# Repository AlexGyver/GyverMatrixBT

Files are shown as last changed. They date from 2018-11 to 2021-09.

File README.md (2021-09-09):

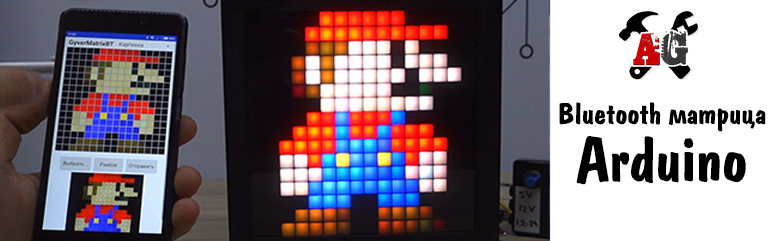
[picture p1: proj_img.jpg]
PROJECT_PHOTO

# Bluetooth адресная матрица на Arduino
* [Описание проекта](#chapter-0)
* [Папки проекта](#chapter-1)
* [Схемы подключения](#chapter-2)
* [Материалы и компоненты](#chapter-3)
* [Как скачать и прошить](#chapter-4)
* [FAQ](#chapter-5)
* [Полезная информация](#chapter-6)
AlexGyver YouTube (https://www.youtube.com/channel/UCgtAOyEQdAyjvm9ATCi_Aig?sub_confirmation=1)

## Описание проекта
Матрица на адресных светодиодах с управлением по Bluetooth  
Гайд по матрицам: https://alexgyver.ru/matrix_guide/  
Страница проекта на сайте: https://alexgyver.ru/gyvermatrixbt/  
Описания к новыем версиям прошивок и приложений смотри на странице проекта    
#### Особенности:
 - Управление со смартфона по Bluetooth
#### Режимы:
 - Рисование
 - Загрузка картинок
 - Бегущая строка  
#### Эффекты:
 - "Дыхание" яркости
 - Смена цвета
 - Снегопад
 - Блуждающий кубик
 - Радуга
 - Огонь
 - The Matrix
 - Летающие частицы
 - Линии  
#### Игры:
 - Змейка
 - Tетриc
 - Лабиринт  
#### Возможности:
- Автоподключение к матрице при запуске
- Настройки яркости и скорости отображения
- Использование акселерометра в играх

## Папки
**ВНИМАНИЕ! Если это твой первый опыт работы с Arduino, читай [инструкцию](#chapter-4)**
- **libraries** - библиотеки проекта. Заменить имеющиеся версии (в этом проекте внешних библиотек нет)
- **firmware** - прошивки для Arduino
- **schemes** - схемы подключения компонентов
- **Android** - файлы с приложениями, примерами для Android и Thunkable
- **3Dprint** - файлы для печати и исходники

## Схемы
SCHEME

## Материалы и компоненты
### Ссылки оставлены на магазины, с которых я закупаюсь уже не один год
Полный список компонентов есть в статье https://alexgyver.ru/matrix_guide/
- Arduino NANO https://ali.ski/RJYuq  https://ali.ski/8JonUm  https://ali.ski/0DIg3
- Bluetooth HC-06 https://ali.ski/nrJ-G  https://ali.ski/0H5Vk  https://ali.ski/xC5vwp
- Матрицы разные https://ali.ski/ft9Y6T
- Лента https://ali.ski/cXIgB1
- Модульная гирлянда https://ali.ski/qrVjv
- Резисторы https://ali.ski/sr6Xy
- БП 5 Вольт https://ali.ski/HkrNAG  https://ali.ski/Y-6VK

## Вам скорее всего пригодится
* [Всё для пайки (паяльники и примочки)](http://alexgyver.ru/all-for-soldering/)
* [Недорогие инструменты](http://alexgyver.ru/my_instruments/)
* [Все существующие модули и сенсоры Arduino](http://alexgyver.ru/arduino_shop/)
* [Электронные компоненты](http://alexgyver.ru/electronics/)
* [Аккумуляторы и зарядные модули](http://alexgyver.ru/18650/)

## Как скачать и прошить
* [Первые шаги с Arduino](http://alexgyver.ru/arduino-first/) - ультра подробная статья по началу работы с Ардуино, ознакомиться первым делом!
* Скачать архив с проектом
> На главной странице проекта (где ты читаешь этот текст) вверху справа зелёная кнопка **Clone or download**, вот её жми, там будет **Download ZIP**
* Установить библиотеки в  
`C:\Program Files (x86)\Arduino\libraries\` (Windows x64)  
`C:\Program Files\Arduino\libraries\` (Windows x86)
* **Подключить внешнее питание 5 Вольт**
* Подключить Ардуино к компьютеру
* Запустить файл прошивки (который имеет расширение .ino)
* Настроить IDE (COM порт, модель Arduino, как в статье выше)
* Настроить что нужно по проекту
* Нажать загрузить
* Скачать GyverMatrixBT с Play Market
* Пользоваться  

## Настройки в коде
    USE_BUTTONS 0       // использовать физические кнопки управления (0 нет, 1 да)
    BUTT_UP 3           // кнопка вверх
    BUTT_DOWN 5         // кнопка вниз
    BUTT_LEFT 2         // кнопка влево
    BUTT_RIGHT 4        // кнопка вправо

    LED_PIN 6           // пин ленты
    BRIGHTNESS 60       // стандартная маскимальная яркость (0-255)

    WIDTH 16            // ширина матрицы
    HEIGHT 16           // высота матрицы

    MATRIX_TYPE 0       // тип матрицы: 0 - зигзаг, 1 - последовательная
    CONNECTION_ANGLE 0  // угол подключения: 0 - левый нижний, 1 - левый верхний, 2 - правый верхний, 3 - правый нижний
    STRIP_DIRECTION 0   // направление ленты из угла: 0 - вправо, 1 - вверх, 2 - влево, 3 - вниз

    SCORE_SIZE 0        // размер букв счёта в игре. 0 - маленький (для 8х8), 1 - большой
    FONT_TYPE 1			// (0 / 1) два вида маленького шрифта

    GLOBAL_COLOR_1 CRGB::Green    // основной цвет №1 для игр
    GLOBAL_COLOR_2 CRGB::Orange   // основной цвет №2 для игр

## FAQ
### Основные вопросы
В: Как скачать с этого грёбаного сайта?  
О: На главной странице проекта (где ты читаешь этот текст) вверху справа зелёная кнопка **Clone or download**, вот её жми, там будет **Download ZIP**

В: Скачался какой то файл .zip, куда его теперь?  
О: Это архив. Можно открыть стандартными средствами Windows, но думаю у всех на компьютере установлен WinRAR, архив нужно правой кнопкой и извлечь.

В: Я совсем новичок! Что мне делать с Ардуиной, где взять все программы?  
О: Читай и смотри видос http://alexgyver.ru/arduino-first/

В: Вылетает ошибка загрузки / компиляции!
О: Читай тут: https://alexgyver.ru/arduino-first/#step-5

В: Сколько стоит?  
О: Ничего не продаю.

### Вопросы по этому проекту

## Полезная информация
* [Мой сайт](http://alexgyver.ru/)
* [Основной YouTube канал](https://www.youtube.com/channel/UCgtAOyEQdAyjvm9ATCi_Aig?sub_confirmation=1)
* [YouTube канал про Arduino](https://www.youtube.com/channel/UC4axiS76D784-ofoTdo5zOA?sub_confirmation=1)
* [Мои видеоуроки по пайке](https://www.youtube.com/playlist?list=PLOT_HeyBraBuMIwfSYu7kCKXxQGsUKcqR)
* [Мои видеоуроки по Arduino](http://alexgyver.ru/arduino_lessons/)

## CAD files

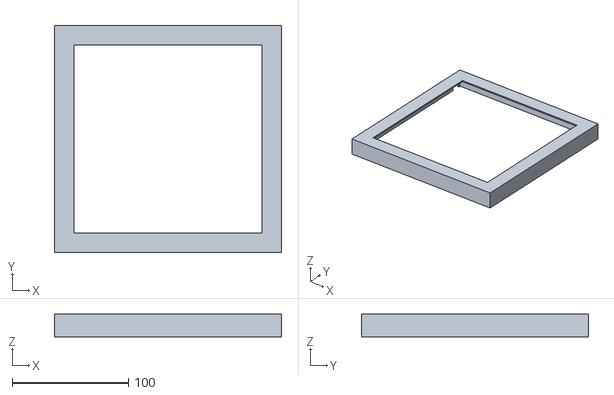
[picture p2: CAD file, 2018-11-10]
3Dprint/Деталь2.stl
195.6 x 195.6 x 19.4

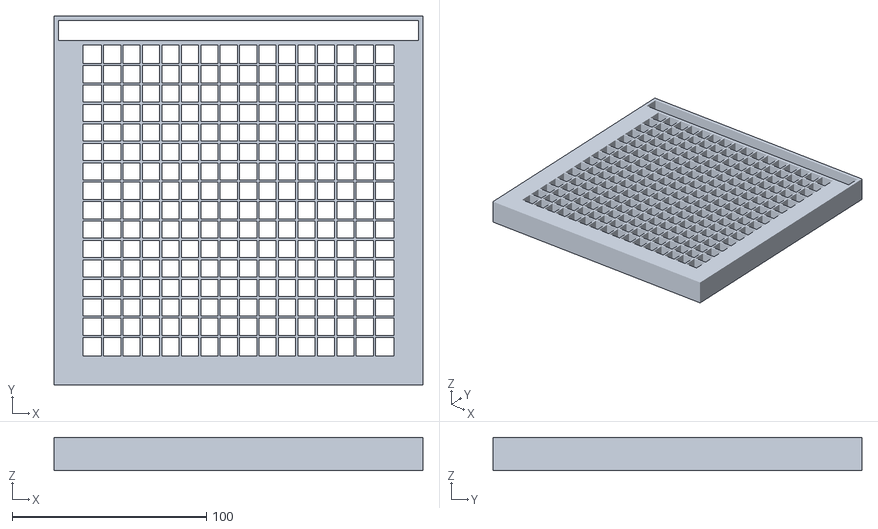
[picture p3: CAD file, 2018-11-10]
3Dprint/Деталь.stl
190.0 x 190.0 x 17.0

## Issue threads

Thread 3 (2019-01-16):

Бегущая строка

lazyan, 2019-01-16:
1. Замечены глюки при отображении бегущей строки. Для устранения комментируем или удаляем:

`FastLED.show();`

в модуле runningText.ino, т.к. он дублируется в custom.ino.

2. В функции drawLetter (модуль runningText.ino) не имеет смысла:

```
...
else drawPixelXY(offset + i, TEXT_HEIGHT + j, 0x000000);
...
else drawPixelXY(i, offset + TEXT_HEIGHT + j, 0x000000);
```

Т.к. до этого экран очищается командой FastLED.clear();

3. Если не использовать блютуз, то скорость прокрутки не зависит от параметра D_TEXT_SPEED из-за условия (модуль runningText.ino):

`if (scrollTimer.isReady() || (!BTcontrol && !gamemodeFlag)) {`

Я просто заменил на:

`if (scrollTimer.isReady()) {`

4. А вообще прикольная хрень )))

buzzik, 2019-12-20:
Подтверждаю глюк на NodeMCU из-за этого бага, закоментил
`    if (offset < -j * (LET_WIDTH + SPACE)) {    // строка убежала
      offset = WIDTH + 3;
      fullTextFlag = true;
    }
    // FastLED.show();
  }`

в модуле runningText.ino

баг пропал, работает отлично. Спасибо Сфори

dimka-36, 2020-02-18:
Целую неделю пытался побороть сей глюк. До сих пор не понимаю как это условие влияло на него :)
 lazyan, спасибо!

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

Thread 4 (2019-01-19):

BT модуль

Irek66, 2019-01-19:
Можно ли для проекта использовать модуль BT типа HM-10 без изменения скетча? А также модуль часов DS1302? Если необходимы изменения, то насколько сложные? Может проще приобрести модули как в проекте.
Спасибо.

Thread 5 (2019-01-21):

Виснет esp8266

SergeyZalozniy, 2019-01-21:
Доброго времени.
Заметил такой баг, не знаю как исправить.
При разных эффектах где используются все диоды esp8266 часто зависает.
Например в режиме радуга или разные "noise", остальные режимы работают отлично весь день.
Спасибо.

SergeyZalozniy, 2019-01-21:
@lazyan а вы сможете сделать fork и залить свои изминеня? Буду очень признателен.

lazyan, 2019-01-21:
Уже!

Best regards,
Anton Horpynich

пн, 21 янв. 2019 г. в 23:47, SergeyZalozniy <notifications@github.com>:

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

lazyan, 2019-01-21:
Уже закомитил

Best regards,
Anton Horpynich

пн, 21 янв. 2019 г. в 23:47, SergeyZalozniy <notifications@github.com>:

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

SergeyZalozniy, 2019-01-22:
Решил проблему.
Оказалось все просто, я использую NodeMCU v3 LoLin,
подключена она напрямую к блоку питания 5v 20a, туда же и лента подключена.
По совету Алекса я поставил напряжение в 4.5v, а по "мануалу" должно быть от 6 - 20v. При включении всей ленты видимо чуток идет просадка, что и приводит к зависанию.
Исправил - отдельное питание для платы помогло.

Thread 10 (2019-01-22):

Вынести прошивку в отдельный репозиторий

Sviatoy, 2019-01-22:
Собственно сейчас, т.к. новая версия делается через добавление ещё одной папки, нет возможности нормально разрабатывать.
Если вынести в отдельный репозиторий, то можно делать релизы. Там можно будет скачивать отдельный архив с одной версией, будет понятно какие изменения

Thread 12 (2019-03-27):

"Нестандартный" размер матрицы

jhnf, 2019-03-27:
Приветствую! Хочу сделать матрицу "нестандартного" размера 4x64 - вдоль крыши дома. Собственно какие из эффектов будут работать на таком размере, а какие нет?

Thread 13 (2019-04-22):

Добавление цветомузыки в качестве эффекта

aka-inc, 2019-04-22:
Есть ли возможность прикрутить эффект цветомузыки? Через микрофон (LineOut) на единственный аналоговый вход ESP8266? Также можно добавить включение следующего эффекта хлопком в ладоши.

Спаял матрицу 15х20 на весь потолок размером 3,8х3,5 метра на микроконтроллере ESP8266-12E, который разместил внутри блока питания 5В 20А. Чтобы избавиться от наводок и глюков, использовал коаксиальный кабель на DIN светодиодной ленты, ферритовое кольцо на линии питания контроллера, обвязку из конденсаторов, а также пришлось понизить напряжение на светодиодах до 4.4В. Глюки проявляются на контрастных режимах с резким переключением яркости диодов, некоторые эффекты вообще не работают, и добавление конденсатора в линию питания контроллера и ленты ничего не даёт. Они явно связаны с всплесками/просадками напряжения при изменении яркости. Может память контроллера заполняется случайным мусором от каких-то наводок. А при пониженном напряжении ничего не глючит, нет спонтанных вспышек и артефактов, но яркость сильно ниже, и цветовой спектр диодов становится очень узкий.  Увеличение расстояния контроллера от блока питания и его экранирование фольгой не влияют на глюки, выпаивал все лишние кнопки, блютузы и прочее, добавлял конденсаторы, менял ESP8266 на ардуину Mega с её 5В питания - ничего не спасает от глюков, только понижение напряжения до 4.4В.

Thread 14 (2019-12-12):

Просьба указать лицензию

smartynov, 2019-12-12:
В настоящее время в репозитории проекта отсутствует указание, по какой лицензии он распространяется (обычно принято это делать в отдельном файле LICENSE). Соответственно, непонятно, является ли этот проект open source и можно ли делать форки проекта и под какой лицензией их распространять. Прошу указать лицензию (рекомендую выбрать MIT).

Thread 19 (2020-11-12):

Проблеми з повзунком "Швидкість"

80Stepko08, 2020-11-12:
1. Мінімальне значення - максимальна швидкість
То ж можна легко поправити 255-знач
Для ігор  то 255-знач множиться на 4 щоб було повільніше
2. Шуми(Божевілля,Хмари і інші) покадрові, хоча можна зробити плавними

Closed 2023-07-04.

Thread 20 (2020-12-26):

В эффектах и бегущей строке не учитывается настройка SEGMENTS

AlexDerev, 2020-12-26:
Если строить матрицу из лент, например 10 х 1м (30 led/м), то матрицу можно расписать как
WIDTH 10
HEIGHT 30
SEGMENTS 1
Или, если хотим уменьшить размер обрабатываемой матрицы (и затраты памяти) и за 1 pix отвечают 2 светодиода, то матрица будет 10х15
WIDTH 10
HEIGHT 15
SEGMENTS 2
Во втором случае во многих эффектах работает только половина матрицы с искажениями, а высота букв в строке так и останется в 8 светодиодов.

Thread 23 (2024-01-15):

Не работает на Mega 2560

P55-rgb, 2024-01-15:
Добрый день.
На нано программа запустилась, добавил диодов, кончилась память, прошил Mega 2560 и не понятно почему не работает блютуз. Без связи по блютуз, Мега 2560 выводит текст на диоды красным цветом КРАСНЫЙ.
Не нашел в описании куда подключать блутуз на Мега 2560.
Подключил блутуз на ТХ0, RX0.

В чём проблема?

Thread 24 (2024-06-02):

Вопрос об другой версии приложения

N-hope, 2024-06-02:
я ранее писал под другим проэктом(из этой же тематики).
У вас на станице проэкта ( https://alexgyver.ru/gyvermatrixbt/ ) есть англоязычная версия. Есть ли возвомность посмотреть ее .aia файл или хотя бы фото всех блоков, как и в других версиях?

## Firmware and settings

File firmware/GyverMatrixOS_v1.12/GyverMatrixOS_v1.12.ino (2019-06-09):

/*
  Скетч к проекту "Адресная матрица"
  Гайд по постройке матрицы: https://alexgyver.ru/matrix_guide/
  Страница проекта (схемы, описания): https://alexgyver.ru/GyverMatrixBT/
  Подробное описание прошивки: https://alexgyver.ru/gyvermatrixos-guide/
  Исходники на GitHub: https://github.com/AlexGyver/GyverMatrixBT/
  Нравится, как написан код? Поддержи автора! https://alexgyver.ru/support_alex/
  Автор: AlexGyver Technologies, 2018
  https://AlexGyver.ru/
*/

// GyverMatrixOS
// Версия прошивки 1.12, совместима с приложением GyverMatrixBT версии 1.12 и выше
// 1.12 - поправлен косяк с кнопкой SET на wemos/nodemcu

// ************************ МАТРИЦА *************************
// если прошивка не лезет в Arduino NANO - отключай режимы! Строка 60 и ниже

#define BRIGHTNESS 150        // стандартная маскимальная яркость (0-255)
#define CURRENT_LIMIT 2000    // лимит по току в миллиамперах, автоматически управляет яркостью (пожалей свой блок питания!) 0 - выключить лимит

#define WIDTH 16              // ширина матрицы
#define HEIGHT 16             // высота матрицы
#define SEGMENTS 1            // диодов в одном "пикселе" (для создания матрицы из кусков ленты)

#define COLOR_ORDER GRB       // порядок цветов на ленте. Если цвет отображается некорректно - меняйте. Начать можно с RGB

#define MATRIX_TYPE 0         // тип матрицы: 0 - зигзаг, 1 - параллельная
#define CONNECTION_ANGLE 0    // угол подключения: 0 - левый нижний, 1 - левый верхний, 2 - правый верхний, 3 - правый нижний
#define STRIP_DIRECTION 0     // направление ленты из угла: 0 - вправо, 1 - вверх, 2 - влево, 3 - вниз
// при неправильной настрйоке матрицы вы получите предупреждение "Wrong matrix parameters! Set to default"
// шпаргалка по настройке матрицы здесь! https://alexgyver.ru/matrix_guide/

#define MCU_TYPE 0            // микроконтроллер: 
//                            0 - AVR (Arduino NANO/MEGA/UNO)
//                            1 - ESP8266 (NodeMCU, Wemos D1)
//                            2 - STM32 (Blue Pill)

// ******************** ЭФФЕКТЫ И РЕЖИМЫ ********************
#define D_TEXT_SPEED 100      // скорость бегущего текста по умолчанию (мс)
#define D_EFFECT_SPEED 80     // скорость эффектов по умолчанию (мс)
#define D_GAME_SPEED 250      // скорость игр по умолчанию (мс)
#define D_GIF_SPEED 80        // скорость гифок (мс)
#define DEMO_GAME_SPEED 60    // скорость игр в демо режиме (мс)

boolean AUTOPLAY = 1;         // 0 выкл / 1 вкл автоматическую смену режимов (откл. можно со смартфона)
int AUTOPLAY_PERIOD = 10;     // время между авто сменой режимов (секунды)
#define IDLE_TIME 10          // время бездействия кнопок или Bluetooth (в секундах) после которого запускается автосмена режимов и демо в играх

// о поддерживаемых цветах читай тут https://alexgyver.ru/gyvermatrixos-guide/
#define GLOBAL_COLOR_1 CRGB::Green    // основной цвет №1 для игр
#define GLOBAL_COLOR_2 CRGB::Orange   // основной цвет №2 для игр

#define SCORE_SIZE 0          // размер символов счёта в игре. 0 - маленький для 8х8 (шрифт 3х5), 1 - большой (шрифт 5х7)
#define FONT_TYPE 1           // (0 / 1) два вида маленького шрифта в выводе игрового счёта

// ************** ОТКЛЮЧЕНИЕ КОМПОНЕНТОВ СИСТЕМЫ (для экономии памяти) *************
// внимание! отключение модуля НЕ УБИРАЕТ его эффекты из списка воспроизведения!
// Это нужно сделать вручную во вкладке custom, удалив ненужные функции

#define USE_BUTTONS 1         // использовать физические кнопки управления играми (0 нет, 1 да)
#define BT_MODE 1             // использовать блютус (0 нет, 1 да)
#define USE_NOISE_EFFECTS 1   // крутые полноэкранные эффекты (0 нет, 1 да) СИЛЬНО ЖРУТ ПАМЯТЬ!!!11
#define USE_FONTS 1           // использовать буквы (бегущая строка) (0 нет, 1 да)
#define USE_CLOCK 0           // использовать часы (0 нет, 1 да)

// игры
#define USE_SNAKE 0           // игра змейка (0 нет, 1 да)
#define USE_TETRIS 0          // игра тетрис (0 нет, 1 да)
#define USE_MAZE 0            // игра лабиринт (0 нет, 1 да)
#define USE_RUNNER 0          // игра бегалка-прыгалка (0 нет, 1 да)
#define USE_FLAPPY 0          // игра flappy bird
#define USE_ARKAN 0           // игра арканоид

// ****************** ПИНЫ ПОДКЛЮЧЕНИЯ *******************
// Arduino (Nano, Mega)
#if (MCU_TYPE == 0)
#define LED_PIN 6           // пин ленты
#define BUTT_UP 3           // кнопка вверх
#define BUTT_DOWN 5         // кнопка вниз
#define BUTT_LEFT 2         // кнопка влево
#define BUTT_RIGHT 4        // кнопка вправо
#define BUTT_SET 7          // кнопка выбор/игра

// пины подписаны согласно pinout платы, а не надписям на пинах!
// esp8266 - плату выбирал Wemos D1 R1
#elif (MCU_TYPE == 1)
#define LED_PIN 2           // пин ленты
#define BUTT_UP 14          // кнопка вверх
#define BUTT_DOWN 13        // кнопка вниз
#define BUTT_LEFT 0         // кнопка влево
#define BUTT_RIGHT 12       // кнопка вправо
#define BUTT_SET 15         // кнопка выбор/игра

// STM32 (BluePill) - плату выбирал STM32F103C
#elif (MCU_TYPE == 2)
#define LED_PIN PB12         // пин ленты
#define BUTT_UP PA1          // кнопка вверх
#define BUTT_DOWN PA3        // кнопка вниз
#define BUTT_LEFT PA0        // кнопка влево
#define BUTT_RIGHT PA2       // кнопка вправо
#define BUTT_SET PA4         // кнопка выбор/игра
#endif

// ******************************** ДЛЯ РАЗРАБОТЧИКОВ ********************************
#define DEBUG 0
#define NUM_LEDS WIDTH * HEIGHT * SEGMENTS

#define RUNNING_STRING 0
#define CLOCK_MODE 1
#define GAME_MODE 2
#define MADNESS_NOISE 3
#define CLOUD_NOISE 4
#define LAVA_NOISE 5
#define PLASMA_NOISE 6
#define RAINBOW_NOISE 7
#define RAINBOWSTRIPE_NOISE 8
#define ZEBRA_NOISE 9
#define FOREST_NOISE 10
#define OCEAN_NOISE 11
#define SNOW_ROUTINE 12
#define SPARKLES_ROUTINE 13
#define MATRIX_ROUTINE 14
#define STARFALL_ROUTINE 15
#define BALL_ROUTINE 16
#define BALLS_ROUTINE 17
#define RAINBOW_ROUTINE 18
#define RAINBOWDIAGONAL_ROUTINE 19
#define FIRE_ROUTINE 20
#define IMAGE_MODE 21

#if (MCU_TYPE == 1)
#define FASTLED_INTERRUPT_RETRY_COUNT 0
#define FASTLED_ALLOW_INTERRUPTS 0
#include <ESP8266WiFi.h>
#endif

#include "FastLED.h"
CRGB leds[NUM_LEDS];
String runningText = "";

static const byte maxDim = max(WIDTH, HEIGHT);
byte buttons = 4;   // 0 - верх, 1 - право, 2 - низ, 3 - лево, 4 - не нажата
int globalBrightness = BRIGHTNESS;
byte globalSpeed = 200;
uint32_t globalColor = 0x00ff00;   // цвет при запуске зелёный
byte breathBrightness;
boolean loadingFlag = true;
byte frameNum;
int gameSpeed = DEMO_GAME_SPEED;
boolean gameDemo = true;
boolean idleState = true;  // флаг холостого режима работы
boolean BTcontrol = false;  // флаг контроля с блютус. Если false - управление с кнопок
int8_t thisMode = 0;
boolean controlFlag = false;
boolean gamemodeFlag = false;
boolean mazeMode = false;
int effects_speed = D_EFFECT_SPEED;
int8_t hrs = 10, mins = 25, secs;
boolean dotFlag;
byte modeCode;    // 0 бегущая, 1 часы, 2 игры, 3 нойс маднесс и далее, 21 гифка или картинка,
boolean fullTextFlag = false;
boolean clockSet = false;

#if (USE_FONTS == 1)
#include "fonts.h"
#endif

uint32_t autoplayTime = ((long)AUTOPLAY_PERIOD * 1000);
uint32_t autoplayTimer;

#include "timerMinim.h"
timerMinim effectTimer(D_EFFECT_SPEED);
timerMinim gameTimer(DEMO_GAME_SPEED);
timerMinim scrollTimer(D_TEXT_SPEED);
timerMinim idleTimer((long)IDLE_TIME * 1000);
timerMinim changeTimer(70);
timerMinim halfsecTimer(500);

#if (USE_CLOCK == 1 && (MCU_TYPE == 0 || MCU_TYPE == 1))
#include <Wire.h>
#include "RTClib.h"

RTC_DS3231 rtc;
// RTC_DS1307 rtc;
#endif

void setup() {
#if (BT_MODE == 1)
  Serial.begin(9600);
#endif

#if (MCU_TYPE == 1)
  WiFi.setSleepMode(WIFI_NONE_SLEEP);
#endif

#if (USE_CLOCK == 1 && (MCU_TYPE == 0 || MCU_TYPE == 1))
  rtc.begin();
  if (rtc.lostPower()) {
    rtc.adjust(DateTime(F(__DATE__), F(__TIME__)));
  }
  DateTime now = rtc.now();
  secs = now.second();
  mins = now.minute();
  hrs = now.hour();
#endif

  // настройки ленты
  FastLED.addLeds<WS2812, LED_PIN, COLOR_ORDER>(leds, NUM_LEDS).setCorrection( TypicalLEDStrip );
  FastLED.setBrightness(BRIGHTNESS);
  if (CURRENT_LIMIT > 0) FastLED.setMaxPowerInVoltsAndMilliamps(5, CURRENT_LIMIT);
  FastLED.clear();
  FastLED.show();
  randomSeed(analogRead(0) + analogRead(1));    // пинаем генератор случайных чисел
}

void loop() {
  customRoutine();
  bluetoothRoutine();
}

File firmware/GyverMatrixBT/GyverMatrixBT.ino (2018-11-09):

/*
  Скетч к проекту "Управляемая RGB матрица"
  Гайд по постройке матрицы: https://alexgyver.ru/matrix_guide/
  Страница проекта (схемы, описания): https://alexgyver.ru/GyverMatrixBT/
  Исходники на GitHub:
  Нравится, как написан код? Поддержи автора! https://alexgyver.ru/support_alex/
  Автор: AlexGyver Technologies, 2018
  http://AlexGyver.ru/
*/

// **************** НАСТРОЙКИ ****************
// чем больше матрица и количество частиц (эффекты) или длина текста (MAX_TEXT),
// тем выше шанс того, что всё зависнет! Выход: юзать Ардуино МЕГА (хотя можно и МИКРО)

#define USE_BUTTONS 0       // использовать физические кнопки управления (0 нет, 1 да)
#define BUTT_UP 3           // кнопка вверх
#define BUTT_DOWN 5         // кнопка вниз
#define BUTT_LEFT 2         // кнопка влево
#define BUTT_RIGHT 4        // кнопка вправо

#define LED_PIN 6           // пин ленты
#define BRIGHTNESS 60       // стандартная маскимальная яркость (0-255)

#define WIDTH 16            // ширина матрицы
#define HEIGHT 16           // высота матрицы

#define MATRIX_TYPE 0       // тип матрицы: 0 - зигзаг, 1 - последовательная
#define CONNECTION_ANGLE 0  // угол подключения: 0 - левый нижний, 1 - левый верхний, 2 - правый верхний, 3 - правый нижний
#define STRIP_DIRECTION 0   // направление ленты из угла: 0 - вправо, 1 - вверх, 2 - влево, 3 - вниз

#define SCORE_SIZE 0        // размер букв счёта в игре. 0 - маленький (для 8х8), 1 - большой
#define FONT_TYPE 1			// (0 / 1) два вида маленького шрифта

#define GLOBAL_COLOR_1 CRGB::Green    // основной цвет №1 для игр
#define GLOBAL_COLOR_2 CRGB::Orange   // основной цвет №2 для игр

// **************** ДЛЯ РАЗРАБОТЧИКОВ ****************
#define DEBUG 0
#define NUM_LEDS WIDTH * HEIGHT

#include "FastLED.h"
CRGB leds[NUM_LEDS];

#define PARSE_AMOUNT 4    // максимальное количество значений в массиве, который хотим получить
#define header '$'        // стартовый символ
#define divider ' '       // разделительный символ
#define ending ';'        // завершающий символ

byte intData[PARSE_AMOUNT];     // массив численных значений после парсинга
uint32_t prevColor;
boolean recievedFlag;
String runningText = "";
byte prevY = 0;
byte prevX = 0;

boolean runningFlag;
boolean loadingFlag;
boolean gameFlag;
boolean effectsFlag;
byte game;
byte effect;
boolean buttons[4];
byte globalBrightness = BRIGHTNESS;;
boolean parseStarted;
byte globalSpeed = 200;
uint32_t globalColor = 0x00ff00;   // цвет при запуске зелёный

#include "GyverTimer.h"
#include "fonts.h"

GTimer_ms effectTimer(100);
GTimer_ms gameTimer(800);
GTimer_ms scrollTimer(100);

#if (USE_BUTTONS == 1)
#include "GyverButton.h"
GButton bt_left(BUTT_RIGHT);
GButton bt_right(BUTT_LEFT);
GButton bt_up(BUTT_UP);
GButton bt_down(BUTT_DOWN);
#endif

//#include <SoftwareSerial.h>
//SoftwareSerial btSerial(12, 13); // TX, RX

void setup() {
  Serial.begin(9600);
  //btSerial.begin(9600);

  // настройки ленты
  FastLED.addLeds<WS2812, LED_PIN, GRB>(leds, NUM_LEDS).setCorrection( TypicalLEDStrip );
  FastLED.setBrightness(BRIGHTNESS);
  FastLED.clear();
  FastLED.show();

  randomSeed(analogRead(0) + analogRead(1));
}

void loop() {
  parsing();       				            // функция парсинга

  if (!parseStarted) {                // на время принятия данных матрицу не обновляем!
    if (runningFlag) fillString();    // бегущая строка
    if (gameFlag) games();            // игры
    if (effectsFlag) effects();       // эффекты
  }
}

boolean checkButtons() {
#if (USE_BUTTONS == 1)
  bt_left.tick();
  bt_right.tick();
  bt_up.tick();
  bt_down.tick();

  if (bt_left.isPress()) {
    buttons[3] = 1;
    return true;
  }
  if (bt_right.isPress()) {
    buttons[1] = 1;
    return true;
  }
  if (bt_up.isPress()) {
    buttons[0] = 1;
    return true;
  }
  if (bt_down.isPress()) {
    buttons[2] = 1;
    return true;
  }
#endif

  for (byte i = 0; i < 4; i++)
    if (buttons[i] != 0) return true;

  return false;
}

// блок эффектов, работают по общему таймеру
void effects() {
  if (effectTimer.isReady()) {
    switch (effect) {
      case 0: brightnessRoutine();
        break;
      case 1: colorsRoutine();
        break;
      case 2: snowRoutine();
        break;
      case 3: ballRoutine();
        break;
      case 4: rainbowRoutine();
        break;
      case 5: rainbowColorsRoutine();
        break;
      case 6: fireRoutine();
        break;
      case 7: matrixRoutine();
        break;
      case 8: ballsRoutine();
        break;
      case 9: wavesRoutine();
        break;
    }
  }
}

// блок игр
void games() {
  switch (game) {
    case 0:
      if (loadingFlag) {
        FastLED.clear();
        loadingFlag = false;
        newGameSnake();
      }
      snakeRoutine();
      break;
    case 1:
      if (loadingFlag) {
        FastLED.clear();
        loadingFlag = false;
        newGameTetris();
      }
      tetrisRoutine();
      break;
    case 2:
      if (loadingFlag) {
        FastLED.clear();
        loadingFlag = false;
        newGameMaze();
      }
      mazeRoutine();
      break;
  }
}

byte index;
String string_convert = "";
enum modes {NORMAL, COLOR, TEXT} parseMode;
byte breathBrightness;
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

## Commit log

2019-01-07 modified frame selection in animation
2019-01-07 added frames enumarating to Superheroes & vgChars
2019-01-07 fixed superheroes.h frames numeration
